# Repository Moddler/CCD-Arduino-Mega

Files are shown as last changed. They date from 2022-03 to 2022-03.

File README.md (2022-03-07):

# CCD-Arduino-Mega

! Work in Progress - Entirely untested !

An Arduino mega shield for interfacing with Chrysler's legacy CCD databus.

This project is a shield for the Arduino Mega 2560. It is designed to hold all the parts necessary to interface with Chrysler's legacy databus CCD, utilized in Chrysler vehicles from the late 80s to late 90s.

The shield can hold a CCD chip in PDIP 14 formfactor, which enables the communication between Arduino Mega and a CCD-databus. For this scenario a quartz oscillator is needed on the PCB.

Known variants/labels of this chip are:

- Intersil CDP68HC68S1E (PDIP 14)
- Harris 4374040 (PDIP 14)
- Harris 306846 (PDIP 14)
- Signetics 4517535 (PDIP 14)

- Intersil CDP68HC68S1M (SOIC 20)
- Philips 4651148 (SOIC 20)
- Philips 04833637 (SOIC 20)
- Signetics 4632650 (SOIC 20)

Additionally, this board can hold the CCDBusTranceiver_v300 from https://github.com/laszlodaniel/CCDBusTransceiver
No oscillator is needed here, this is the preferred method.

There are three jumpers available for setting bus termination and bus bias voltage.

A pushbutton and two LEDs are also available for whatever one could use them.

There is no specific software available at this point.

This device is meant to be able to tinker with ECUs/BCMs/EATX-Controllers etc. on a testbench, without having to worry about the circuits around the CCD interfacing-chip.

It probably can also be used to sniff CCD messages in a vehicle, or trigger diagnostic commands.
It is not a full blown diagnostic device and will never be, since it is missing some other features Chrysler used in old vehicles.

The board is powered via the USB connection of the Arduino, and also enables the serial communication with a serial console or program.
The simplest way to get started is to use the serial passthrough example sketch and set the baud rate communication to the chip to 7812,5 Baud (CCD bus baud speed).

Related and highly respected work:

Juha Niinikoski
http://www.kolumbus.fi/juha.niinikoski/CCD_bus/ccd_display.htm

Boundary Condition / László Dániel
https://chryslerccdsci.wordpress.com
https://github.com/laszlodaniel/ChryslerCCDSCIScanner
https://github.com/laszlodaniel/CCDLibrary
https://github.com/laszlodaniel/CCDBusTransceiver

Geoff / moparchem.com / Ladybug / Dcal

ShelGame at turbo-mopar.com
http://www.turbo-mopar.com/forums/member.php?141-ShelGame

wowzer at turbo-mopar.com
http://www.turbo-mopar.com/forums/member.php?1068-wowzer

majekw
https://github.com/majekw/sigrok-ccd-pd

xerootg
https://github.com/xerootg

NickInTimeDesign
https://nickintimedesign.com

AR1972
https://github.com/AR1972/jeep_2.5L

MWisBest
https://github.com/MWisBest/DRBDBReader

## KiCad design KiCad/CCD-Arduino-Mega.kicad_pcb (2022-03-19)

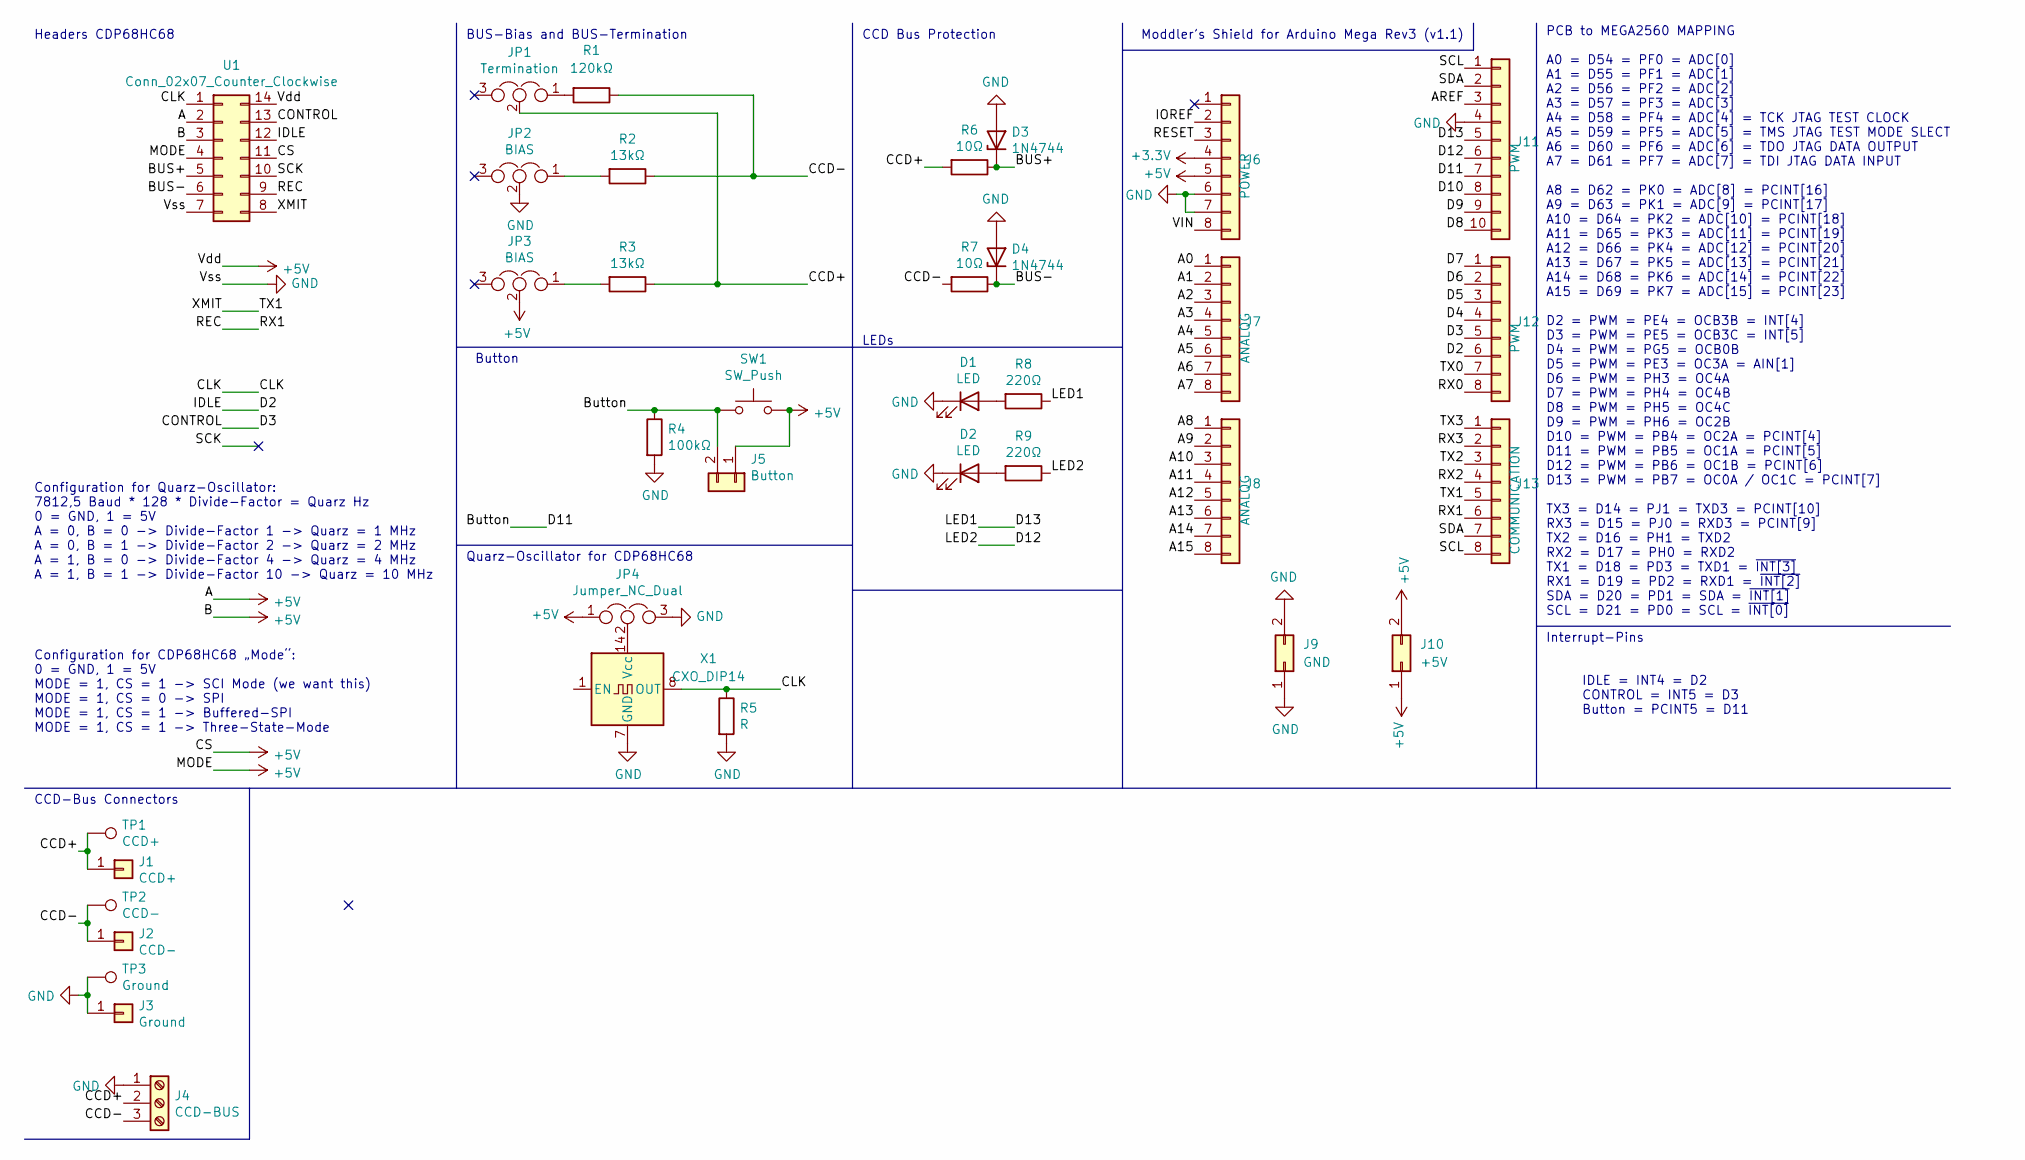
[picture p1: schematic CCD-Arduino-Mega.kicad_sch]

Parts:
D1, D2: LED; LED_D5.0mm
D3, D4: 1N4744; D_DO-41_SOD81_P7.62mm_Horizontal
J1: CCD+; PinSocket_1x01_P2.54mm_Vertical
J2: CCD-; PinSocket_1x01_P2.54mm_Vertical
J3: Ground; PinSocket_1x01_P2.54mm_Vertical
J4: CCD-BUS; TerminalBlock_Phoenix_MPT-0,5-3-2.54_1x03_P2.54mm_Horizontal
J5: Button; PinHeader_1x02_P2.54mm_Vertical
J6: POWER; PinHeader_1x08_P2.54mm_Vertical
J7, J8: ANALOG; PinHeader_1x08_P2.54mm_Vertical
J9: GND; PinHeader_2x01_P2.54mm_Vertical
J10: +5V; PinHeader_2x01_P2.54mm_Vertical
J11: PWM; PinHeader_1x10_P2.54mm_Vertical
J12: PWM; PinHeader_1x08_P2.54mm_Vertical
J13: COMMUNICATION; PinHeader_1x08_P2.54mm_Vertical
JP1: Termination; PinHeader_1x03_P2.54mm_Vertical
JP2, JP3: BIAS; PinHeader_1x03_P2.54mm_Vertical
JP4: Jumper_NC_Dual; PinHeader_1x03_P2.54mm_Vertical
R1: 120kΩ; R_Axial_DIN0207_L6.3mm_D2.5mm_P7.62mm_Horizontal
R2, R3: 13kΩ; R_Axial_DIN0207_L6.3mm_D2.5mm_P7.62mm_Horizontal
R4: 100kΩ; R_Axial_DIN0207_L6.3mm_D2.5mm_P7.62mm_Horizontal
R5: R; R_Axial_DIN0207_L6.3mm_D2.5mm_P7.62mm_Horizontal
R6, R7: 10Ω; R_Axial_DIN0207_L6.3mm_D2.5mm_P7.62mm_Horizontal
R8, R9: 220Ω; R_Axial_DIN0207_L6.3mm_D2.5mm_P7.62mm_Horizontal
SW1: SW_Push; SW_PUSH_6mm
TP1: CCD+; TestPoint_Pad_D3.0mm
TP2: CCD-; TestPoint_Pad_D3.0mm
TP3: Ground; TestPoint_Pad_D3.0mm
U1: Conn_02x07_Counter_Clockwise; DIP-14_W7.62mm
X1: CXO_DIP14; Oscillator_DIP-14

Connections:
+3V3: J6.4
+5V: J5.1, J6.5, J10.1, J10.2, JP3.2, JP4.1, SW1.2, U1.2, U1.3, U1.4, U1.11, U1.14
/A0: J7.1
/A1: J7.2
/A2: J7.3
/A3: J7.4
/A4: J7.5
/A5: J7.6
/A6: J7.7
/A7: J7.8
/A8: J8.1
/A9: J8.2
/A10: J8.3
/A11: J8.4
/A12: J8.5
/A13: J8.6
/A14: J8.7
/A15: J8.8
/AREF: J11.3
/BUS+: D3.1 (K), R6.1, U1.5
/BUS-: D4.1 (K), R7.1, U1.6
/Button: J5.2, J11.7, R4.1, SW1.1
/CCD+: J1.1, J4.2, JP1.2, R3.1, R6.2, TP1.1
/CCD-: J2.1, J4.3, R1.1, R2.1, R7.2, TP2.1
/CLK: R5.1, U1.1, X1.8 (OUT)
/CONTROL: J12.5, U1.13
/D2: J12.6, U1.12
/D4: J12.4
/D5: J12.3
/D6: J12.2
/D7: J12.1
/D8: J11.10
/D9: J11.9
/D10: J11.8
/D12: J11.6, R9.1
/D13: J11.5, R8.1
/IOREF: J6.2
/REC: J13.6, U1.9
/RESET: J6.3
/RX0: J12.8
/RX2: J13.4
/RX3: J13.2
/SCK: U1.10
/SCL: J11.1, J13.8
/SDA: J11.2, J13.7
/TX0: J12.7
/TX1: J13.5, U1.8
/TX2: J13.3
/TX3: J13.1
/VIN: J6.8
GND: D1.1 (K), D2.1 (K), D3.2 (A), D4.2 (A), J3.1, J4.1, J6.6, J6.7, J9.1, J9.2, J11.4, JP2.2, JP4.3, R4.2, R5.2, TP3.1, U1.7, X1.7 (GND)
unnamed: D1.2 (A), R8.2
unnamed: D2.2 (A), R9.2
unnamed: JP1.1, R1.2
unnamed: JP2.1, R2.2
unnamed: JP3.1, R3.2
unnamed: JP4.2, X1.14 (Vcc)

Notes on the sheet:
LEDs
Quarz-Oscillator for CDP68HC68
IDLE = INT4 = D2 CONTROL = INT5 = D3 Button = PCINT5 = D11
Configuration for Quarz-Oscillator: 7812,5 Baud * 128 * Divide-Factor = Quarz Hz 0 = GND, 1 = 5V A = 0, B = 0 -> Divide-Factor 1 -> Quarz = 1 MHz A = 0, B = 1 -> Divide-Factor 2 -> Quarz = 2 MHz A = 1, B = 0 -> Divide-Factor 4 -> Quarz = 4 MHz A = 1, B = 1 -> Divide-Factor 10 -> Quarz = 10 MHz
Interrupt-Pins
CCD-Bus Connectors
Button
BUS-Bias and BUS-Termination
PCB to MEGA2560 MAPPING A0 = D54 = PF0 = ADC[0] A1 = D55 = PF1 = ADC[1] A2 = D56 = PF2 = ADC[2] A3 = D57 = PF3 = ADC[3] A4 = D58 = PF4 = ADC[4] = TCK JTAG TEST CLOCK A5 = D59 = PF5 = ADC[5] = TMS JTAG TEST MODE SLECT A6 = D60 = PF6 = ADC[6] = TDO JTAG DATA OUTPUT A7 = D61 = PF7 = ADC[7] = TDI JTAG 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
CCD Bus Protection
Configuration for CDP68HC68 „Mode“: 0 = GND, 1 = 5V MODE = 1, CS = 1 -> SCI Mode (we want this) MODE = 1, CS = 0 -> SPI MODE = 1, CS = 1 -> Buffered-SPI MODE = 1, CS = 1 -> Three-State-Mode
Headers CDP68HC68
Moddler’s Shield for Arduino Mega Rev3 (v1.1)

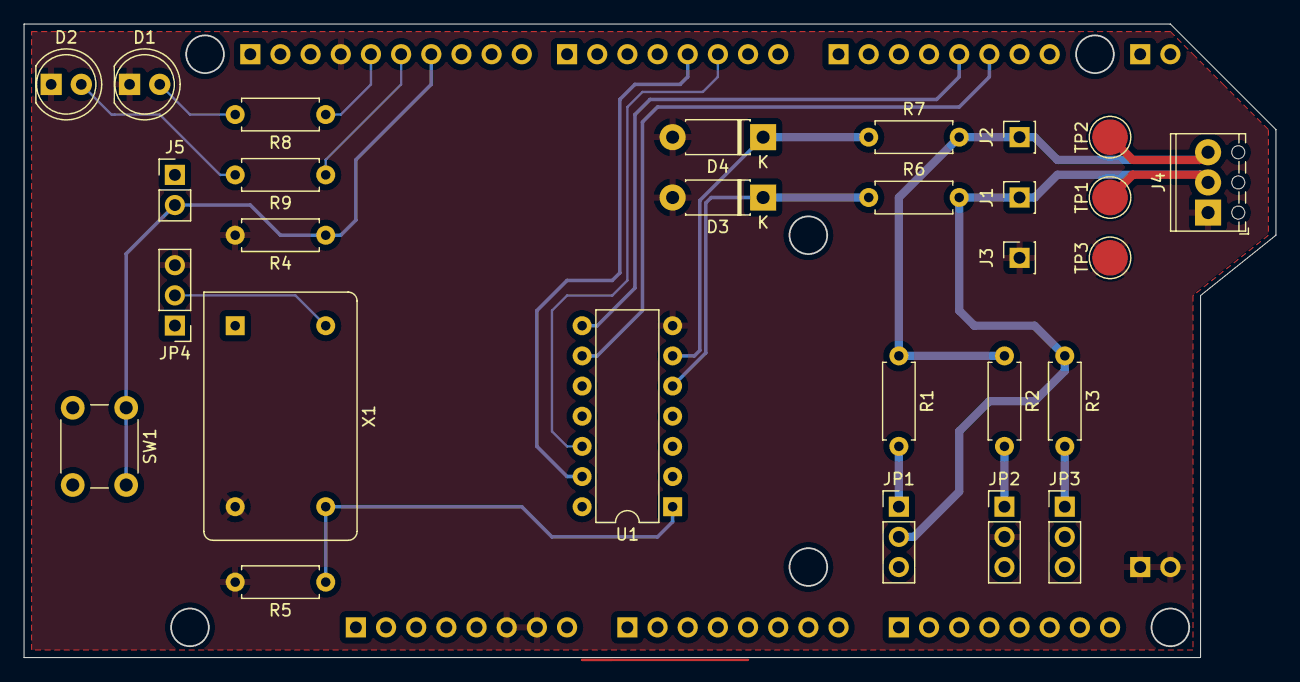
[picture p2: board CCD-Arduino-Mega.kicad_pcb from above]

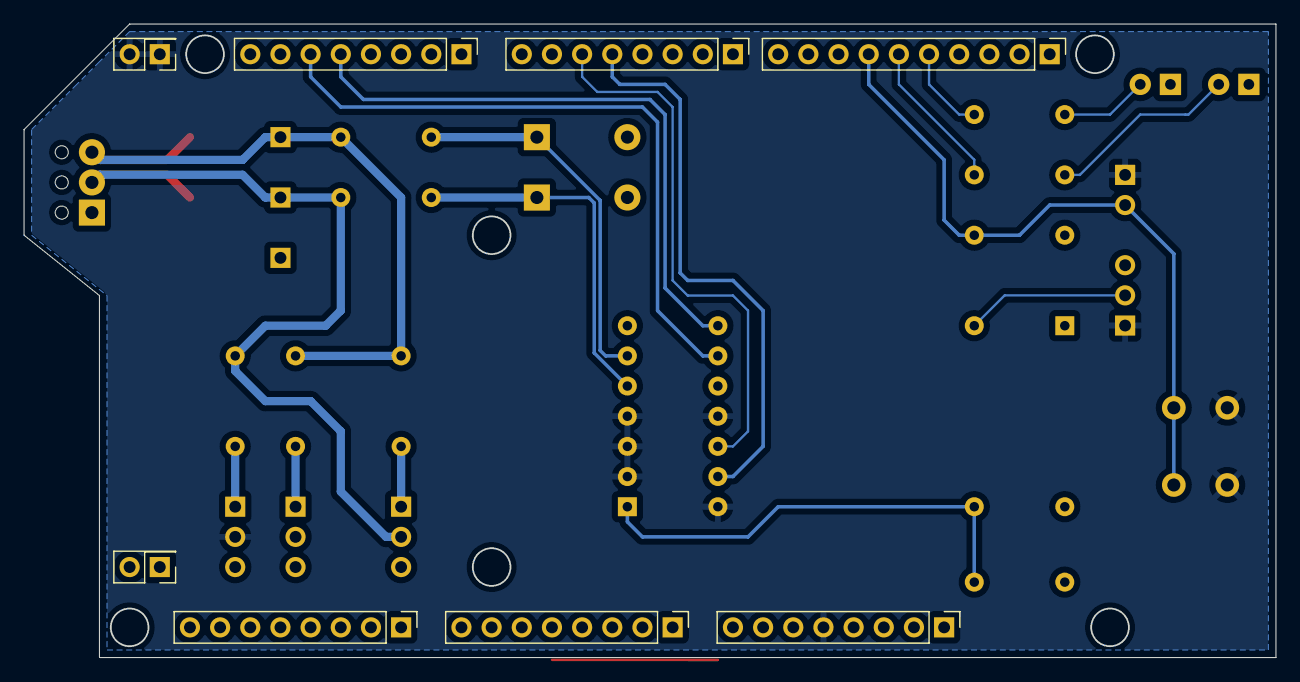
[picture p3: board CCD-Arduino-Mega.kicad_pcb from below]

Board: 2 copper layers, 105.4 x 53.3 mm, 36 parts (8 on the bottom side), 22 nets.

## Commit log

2022-03-07 reboot and update to KiCAD v7
    [CCD-Arduino-Mega.kicad_pcb, CCD-Arduino-Mega.kicad_sch]
2022-03-19 reboot and update to KiCAD v6
    [CCD-Arduino-Mega.kicad_pcb, CCD-Arduino-Mega.kicad_sch]
